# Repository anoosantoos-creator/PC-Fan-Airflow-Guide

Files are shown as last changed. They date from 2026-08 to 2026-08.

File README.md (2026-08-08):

# PC Fan Airflow Guide

A measured 120 mm intake-fan project comparing three internal airflow guides. The repository contains parametric CAD, printable STEP/STL exports, complete OpenFOAM 13 cases, raw rerun evidence, and scripts that recalculate every published table and figure.

The goal is narrow: determine which concepts are worth printing and testing. The CFD does **not** prove lower CPU or GPU temperatures.

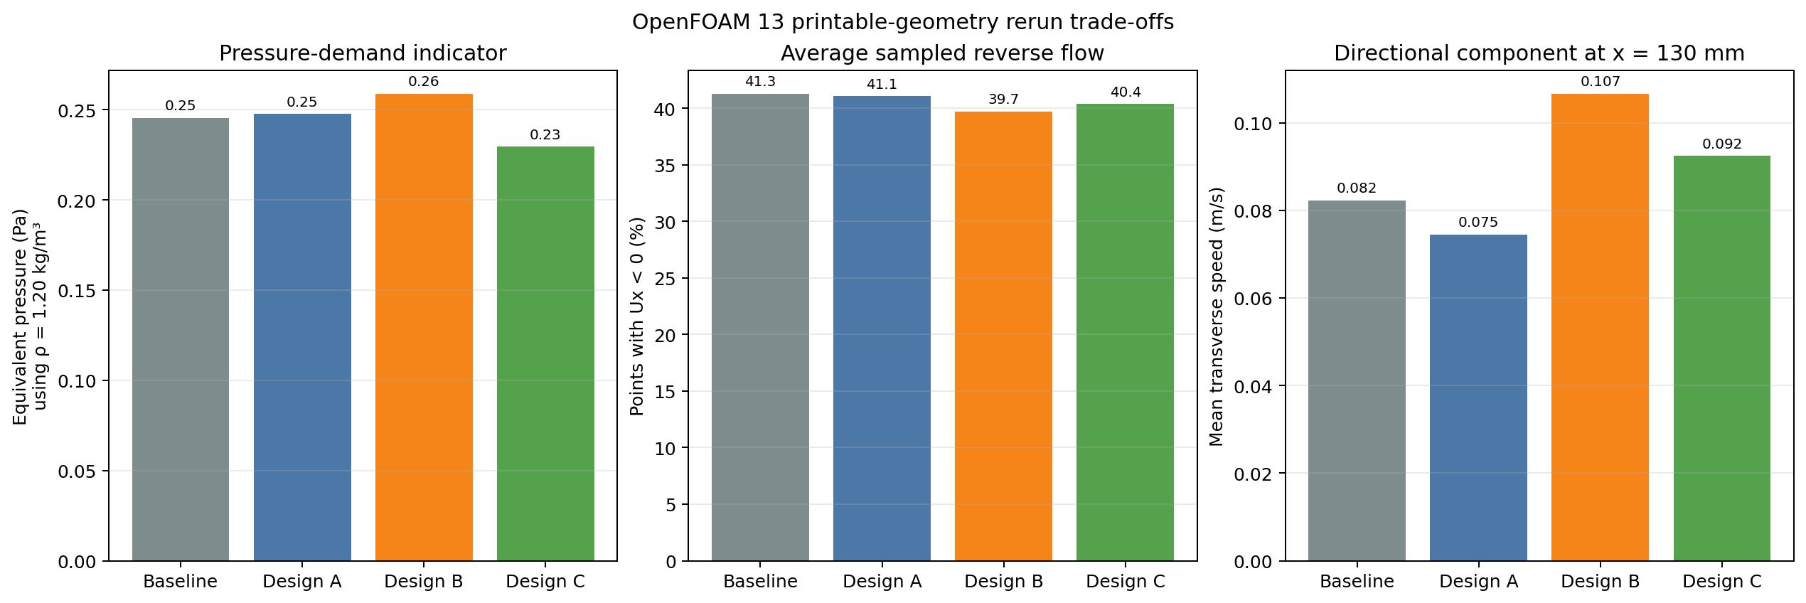
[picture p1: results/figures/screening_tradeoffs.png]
CFD screening trade-offs


## Current result

The printable-geometry rerun leaves two useful physical prototypes:

- **Design A** is the straight-vane control. It has low printable blockage and the smallest mean transverse component at the 130 mm target plane.
- **Design C** is the balanced directional candidate. It has the lowest pressure-demand indicator, low printable blockage, and a transverse component between A and B at 130 mm.
- **Design B** remains the aggressive comparison. It has the lowest average reverse-flow fraction, but also the highest blockage, pressure-demand indicator, and 130 mm transverse component among the guides.

No design is declared final. The next decision requires a baseline-versus-A-versus-C physical test.

| Case | Printable blockage estimate | Pressure-demand indicator* | Mean reverse-flow samples | Transverse speed at 130 mm |
|---|---:|---:|---:|---:|
| Baseline | 0.00% | 0.245 Pa | 41.3% | 0.0823 m/s |
| Design A | 3.95% | 0.248 Pa | 41.1% | 0.0745 m/s |
| Design B | 7.02% | 0.259 Pa | 39.7% | 0.1066 m/s |
| Design C | 3.56% | 0.229 Pa | 40.4% | 0.0924 m/s |

\* OpenFOAM stores kinematic pressure for this incompressible setup. The table converts the sampled pressure difference using an assumed air density of 1.20 kg/m³. Treat it as a comparison indicator, not a fan-pressure measurement.

The full calculation is in [`results/cfd_summary.csv`](results/cfd_summary.csv). Mean axial velocity at 350 mm is within 0.01% across all four cases because the closed duct and equal inlet flow constrain that plane average; it is a mass-flow check, not a design-ranking metric. All four runs reached the 800-iteration limit before satisfying every strict residual control, and no mesh-independence study has been completed. Those limitations are carried into the decision instead of being hidden.

## Designs

| Design | Depth | Vanes | Bias | Vane thickness | Intended role |
|---|---:|---:|---:|---:|---|
| A — low blockage | 20 mm | 6 | 0° | 1.50 mm | Straight-vane control candidate |
| B — angled guide | 25 mm | 8 | 14° | 2.00 mm | High-blockage comparison |
| C — balanced revision | 22 mm | 6 | 9° | 1.35 mm | Balanced directional candidate |

All three printable exports are single connected solids, watertight, manifold, and confined to their declared depth. The vanes overlap both the central hub and outer frame so they do not float as separate bodies.

## Rebuild and check

Requirements:

- Node.js 20 or newer for CAD export
- Python 3.10 or newer for analysis
- OpenFOAM 13 only when rebuilding the CFD solutions

```bash
npm ci
python -m pip install -r requirements.txt
npm run check
```

Individual commands:

```bash
npm run cad
npm run cfd:prepare
npm run analysis
npm run validate
```

To rebuild the meshes and solutions from a clean OpenFOAM 13 shell:

```bash
CFD_JOBS=4 CFD_RUN_ROOT=/path/to/new/run-directory npm run cfd:run
npm run cfd:collect -- /path/to/new/run-directory
npm run analysis
npm run validate
```

The validation step checks STL envelopes and topology, complete case inputs, CAD-to-CFD geometry identity, raw solver evidence, recalculated CFD values, local document links, and the public tree.

## Repository map

- [`cad_designs/`](cad_designs/) — printable STEP/STL files and a dimensional fan reference
- [`scripts/generate_cad.cjs`](scripts/generate_cad.cjs) — parametric CAD source
- [`openfoam_cases/`](openfoam_cases/) — complete OpenFOAM inputs and one-command case runners
- [`data/`](data/) — current and original OpenFOAM target-plane samples and run logs
- [`scripts/run_openfoam_cases.sh`](scripts/run_openfoam_cases.sh) — clean four-case meshing, solving, and sampling pipeline
- [`scripts/analyze_openfoam_samples.py`](scripts/analyze_openfoam_samples.py) — table and figure generation
- [`results/`](results/) — corrected summaries, mesh checks, residuals, and figures
- [`docs/measurements.md`](docs/measurements.md) — measured fan and case constraints
- [`docs/cfd_method.md`](docs/cfd_method.md) — numerical method, provenance, and limitations
- [`docs/physical_test_plan.md`](docs/physical_test_plan.md) — repeatable prototype test procedure
- [`docs/sources.md`](docs/sources.md) — technical references

## Safety and scope

Power the PC down before installation. Confirm blade clearance by hand, secure the guide mechanically, and stop testing if the guide shifts, touches the rotor, or causes abnormal vibration or temperature.

This is an airflow-screening and prototyping project. It is not a certified thermal product or a universal fit for every 120 mm fan.

## License

Released under the [MIT License](LICENSE).

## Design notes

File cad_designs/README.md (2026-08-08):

# CAD Files

All dimensions are millimeters. The x-axis is guide depth; the y-z plane is the 120 × 120 mm fan face.

| File pair | Description | Print status |
|---|---|---|
| `design_A_low_blockage` | 20 mm, six straight 1.5 mm vanes | First-cycle prototype candidate |
| `design_B_angled_guide` | 25 mm, eight 14° biased 2.0 mm vanes | Comparison design; lower priority |
| `design_C_balanced_revision` | 22 mm, six 9° biased 1.35 mm vanes | First-cycle prototype candidate |
| `fan_reference` | Dimensional frame and hub reference | Reference assembly, not a print recommendation |

The three guide STLs are each one connected, watertight manifold component. Their vanes overlap the hub and frame before the final Boolean union. `fan_reference` intentionally contains a separate hub because it represents the fan's inactive center rather than a printable guide.

Regenerate the exports from the repository root:

```bash
npm install
npm run cad
```

Print the guide with a 120 × 120 mm face on the bed and inspect the slicer preview before committing material. Hole fit, screw length, material choice, fan clearance, and case-specific mounting still require a physical check.

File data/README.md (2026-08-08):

# OpenFOAM evidence

The current printable-geometry rerun is stored in `rerun_v2/`:

- `run_manifest.json` records the OpenFOAM build, final iteration, convergence
  status, mesh check, and sampled time for every case.
- `openfoam_logs/` contains the complete meshing, patch-creation, mesh-check,
  solver, and sampling logs.
- `openfoam_samples/` contains the raw x-y-z position, velocity components,
  and kinematic pressure on fixed 50 × 50 grids at the 100, 130, and 350 mm
  target planes.

Each target-plane `.xy` file has seven columns:

```text
point_x point_y point_z U_x U_y U_z p
```

The top-level `openfoam_logs/` and `openfoam_samples/` directories preserve the
original 200-iteration v1 screening evidence. They are retained for provenance
but are no longer the source for the published tables and figures. The v1
printable connectors were revised after those runs, and its original case
dictionaries were unavailable.

The complete v2 inputs are tracked in [`../openfoam_cases/`](../openfoam_cases/).
After a clean solve, `npm run cfd:collect -- /path/to/run-directory` rebuilds
`rerun_v2/` from the completed run. Run `npm run analysis` to rebuild the
public results from that evidence.

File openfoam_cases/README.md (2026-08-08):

# Complete OpenFOAM cases

This directory contains the complete inputs for the current OpenFOAM 13 rerun.
Each case includes initial fields, physical and turbulence properties, meshing
dictionaries, the metre-scale obstruction STL, solver controls, sampling
controls, and an executable `Allrun` script.

| Case | Solid geometry |
|---|---|
| `baseline_no_guide` | Measured fan frame and inactive hub |
| `design_A_low_blockage` | Current connected Design A STL |
| `design_B_angled_guide` | Current connected Design B STL |
| `design_C_balanced_revision` | Current connected Design C STL |

## Rebuild the cases

The tracked case surfaces are deterministic metre-scale copies of the
printable STLs:

```bash
npm run cad
npm run cfd:prepare
```

## Run all four cases

Start an OpenFOAM 13 shell, then run:

```bash
CFD_JOBS=4 CFD_RUN_ROOT=/path/to/new/run-directory npm run cfd:run
```

`CFD_JOBS` may be 1 through 4. The run directory must not already exist. A
temporary directory is created when `CFD_RUN_ROOT` is omitted.

To run one case in place instead:

```bash
cd openfoam_cases/design_A_low_blockage
./Allrun
```

The pipeline executes `blockMesh`, `surfaceCheck`, `snappyHexMesh`,
`createPatch`, `checkMesh`, `foamRun -solver incompressibleFluid`, and
`foamPostProcess`. The native `createPatch` step separates the active
20--52.5 mm inlet annulus from the blocked fan-face area without compiled
boundary code.

## Numerical layout

- Domain: x = -4 to 396 mm; y and z = -100 to 100 mm
- Base mesh: 4 mm cells; local guide refinement down to about 1 mm
- Inlet: 2.5 m/s on the active annulus; blocked elsewhere
- Outlet: fixed kinematic pressure at zero
- Walls and solid geometry: no slip
- Model: steady incompressible RANS with `kOmegaSST`
- Limit: 800 iterations, with residual controls for earlier termination
- Samples: raw `U` and `p` on fixed 50 × 50 grids at x = 100, 130, and 350 mm

Generated meshes and volume fields are run outputs, not case inputs, and are
therefore kept out of the tracked case directories. The dictionaries and
surfaces needed to regenerate them are all included.

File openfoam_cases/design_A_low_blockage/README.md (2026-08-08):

# Design A OpenFOAM case

Current connected 20 mm guide with six straight vanes.

The tracked obstruction surface is a metre-scaled copy of
`cad_designs/design_A_low_blockage.stl`. Run `./Allrun` from an OpenFOAM 13
shell to mesh, solve, and sample the 100, 130, and 350 mm planes.

Case identifier: `design_A_low_blockage`

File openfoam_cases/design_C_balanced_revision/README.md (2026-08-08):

# Design C OpenFOAM case

Current connected 22 mm guide with six 9 degree vanes.

The tracked obstruction surface is a metre-scaled copy of
`cad_designs/design_C_balanced_revision.stl`. Run `./Allrun` from an OpenFOAM 13
shell to mesh, solve, and sample the 100, 130, and 350 mm planes.

Case identifier: `design_C_balanced_revision`

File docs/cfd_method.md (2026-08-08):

# CFD Method

## Question

How do three short guide geometries change the sampled downstream velocity
field and pressure-demand indicator of a measured 120 mm intake-fan setup?

The model screens concepts for prototyping. It does not predict component
temperature.

## Current geometry

The v2 rerun uses the current printable solids rather than the disconnected
vane bodies from the first screening pass.

- Baseline: measured 25 mm fan frame and inactive 40 mm hub
- Design A: current connected 20 mm, six-vane STL
- Design B: current connected 25 mm, eight-vane STL
- Design C: current connected 22 mm, six-vane STL

Every tracked simulation surface is a deterministic metre-scale copy of its
source STL in `cad_designs/`. `surfaceCheck` reports every surface closed; the
three printable guides are each one connected part. The baseline frame and hub
are intentionally two closed parts.

## Domain and boundaries

- Rectangular domain: x = -4 to 396 mm; y and z = -100 to 100 mm
- Physical fan/guide plane: x = 0 mm
- Target planes: x = 100, 130, and 350 mm
- Active inlet annulus: radius 20--52.5 mm
- Active-annulus velocity: 2.5 m/s in the +x direction
- Blocked inlet area, duct sides, and solids: no-slip walls
- Outlet: zero kinematic pressure with an inlet/outlet velocity condition

The 4 mm inlet offset prevents the obstruction surface from being coincident
with a velocity boundary. Extending the outlet to 396 mm keeps the 350 mm
target plane inside the volume instead of sampling on the outlet boundary.
`createPatch` makes the active annulus from native mesh faces, so the setup
does not require compiled boundary code.

The case, cables, coolers, filter, rotor blades, thermal sources, and
manufacturer fan curve are absent. The nominal inlet velocity remains an
equal-input assumption.

## Flow model

- OpenFOAM 13, build recorded in `data/rerun_v2/run_manifest.json`
- Steady incompressible solver module (`foamRun -solver incompressibleFluid`)
- `kOmegaSST` RANS turbulence model
- Kinematic viscosity: 1.5e-5 m²/s
- Inlet turbulence intensity: 5%
- Turbulence mixing length: 4.55 mm
- Maximum 800 SIMPLE iterations
- Residual controls: p = 1e-4; U, k, and omega = 1e-5

The solver can terminate before iteration 800 only when all residual controls
are satisfied. The manifest and residual table distinguish convergence from an
iteration-limit stop for each case. All four published runs reached iteration
800 before satisfying every control; the last residuals remain available in
[`../results/solver_residual_summary.csv`](../results/solver_residual_summary.csv).

## Mesh and sampling

The background mesh uses 4 mm hexahedra. Cells around the fan and guides are
refined, with surface cells down to about 1 mm. Boundary layers are not added.
The pipeline is:

1. `blockMesh`
2. `surfaceCheck`
3. `snappyHexMesh`
4. `createPatch`
5. `checkMesh`
6. `foamRun -solver incompressibleFluid`
7. `foamPostProcess -dict system/sampleDict -latestTime`

All four standard `checkMesh` runs must report `Mesh OK` before their results
are collected. The detailed cell count and quality values are extracted into
[`../results/mesh_quality_summary.csv`](../results/mesh_quality_summary.csv).

The post-processor interpolates `U` and kinematic `p` onto a fixed 50 × 50
cell-center grid at each target plane. The y and z coordinates run from
-98 to 98 mm at 4 mm spacing, so every case is compared at the same 2,500
locations regardless of local mesh refinement. Each row has seven columns:

```text
point_x point_y point_z U_x U_y U_z p
```

## Published metrics

For each plane, the analysis calculates:

- mean axial velocity, mean velocity magnitude, and mean transverse speed
- fraction of points with negative axial velocity
- mean kinematic pressure
- downstream axial retention relative to the v2 baseline

Because every case has the same fixed inlet flow and a closed duct, the
whole-plane downstream mean axial velocity is expected to be nearly identical.
Axial retention is therefore a mass-flow consistency check, not a design
ranking metric. Pressure demand, reverse-flow sampling, and transverse-speed
differences provide the comparative screen.

The pressure-demand indicator is

\[
\left|\overline{p}_{100}-\overline{p}_{350}\right|.
\]

OpenFOAM stores kinematic pressure for this setup. The table multiplies the
indicator by an assumed air density of 1.20 kg/m³ to show an equivalent
pressure in pascals. It is a comparison inside this model, not a fan-pressure
measurement.

## Reproduction

The complete v2 cases are included in [`../openfoam_cases/`](../openfoam_cases/).
They contain every initial field, physical property, turbulence setting,
meshing dictionary, solver control, sampling control, and obstruction surface
needed to rebuild the meshes and rerun the solves. `npm run cfd:run` executes
all four cases; [`../scripts/run_openfoam_cases.sh`](../scripts/run_openfoam_cases.sh)
is the command-level record.

Raw v2 logs and sampled fields are under [`../data/rerun_v2/`](../data/rerun_v2/).
The original v1 evidence remains under the top-level data directories for
provenance, but it is not used for the current figures or tables.

## Interpretation boundary

The rerun supports equal-input comparison of these four local duct models. It
does not establish temperature improvement, a real fan operating point, mesh
independence, turbulence-model independence, or universal fit. A physical
baseline-versus-prototype test remains the deciding experiment.

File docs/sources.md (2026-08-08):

# Technical Sources

## OpenFOAM

- [OpenFOAM 13 release and platform downloads](https://openfoam.org/version/13/)
- [OpenFOAM 13 installation on Ubuntu](https://openfoam.org/download/13-ubuntu/)
- [OpenFOAM on Windows through WSL](https://openfoam.org/download/windows/)
- [OpenFOAM v13 solver modules](https://doc.cfd.direct/openfoam/user-guide-v13/solvers-modules)
- [SIMPLE and solution controls](https://doc.cfd.direct/openfoam/user-guide-v13/fvsolution)
- [`snappyHexMesh` workflow and mesh controls](https://doc.cfd.direct/openfoam/user-guide-v13/snappyhexmesh)
- [Post-processing surfaces and streamlines](https://doc.cfd.direct/openfoam/user-guide-v13/post-processing-functionality)

## Turbulence model

- F. R. Menter, “Two-Equation Eddy-Viscosity Turbulence Models for Engineering Applications,” *AIAA Journal*, 32(8), 1598–1605, 1994. [DOI: 10.2514/3.12149](https://doi.org/10.2514/3.12149)

## Parametric CAD

- [Replicad library setup](https://replicad.xyz/docs/use-as-a-library)
- [Replicad solid export API](https://replicad.xyz/docs/api/classes/Solid/)

## Project-specific evidence

- Direct fan and case measurements are recorded in [`measurements.md`](measurements.md).
- The nominal inlet velocity is an explicit model assumption, not a manufacturer specification.
- Raw sampled fields and solver logs are preserved under [`../data/`](../data/).
- Recalculated tables and residual summaries are preserved under [`../results/`](../results/).

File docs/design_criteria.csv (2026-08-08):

Criterion | Threshold or question | Design A | Design B | Design C | Current evidence
Fit envelope | Remain within the measured 20-25 mm allowance | 20 mm | 25 mm | 22 mm | STL envelopes verified automatically
Single printable body | No floating hub or vane solids | Pass | Pass | Pass | Each guide is one manifold connected component
Geometric blockage | Keep active-annulus obstruction low | 3.95% estimate | 7.02% estimate | 3.56% estimate | Calculated from printable vane span and thickness
Pressure demand | Prefer a lower comparative demand | 0.248 Pa indicator | 0.259 Pa indicator | 0.229 Pa indicator | Design C is lowest in the printable-geometry rerun
Reverse-flow samples | Prefer fewer sampled points with Ux below zero | 41.1% | 39.7% | 40.4% | Average across x=100/130/350 mm; Design B is lowest
Target-plane direction | Compare mean transverse speed at x=130 mm | 0.0745 m/s | 0.1066 m/s | 0.0924 m/s | A is straightest; B is strongest; C is intermediate
Printability | Use robust vane thickness and a flat build orientation | Needs slicer and print check | Lower priority due to thickness and blockage | Needs slicer and print check | CAD topology passes but no physical print is recorded
Mounting | Use positive retention at measured 105 mm spacing | Through-holes | Through-holes | Through-holes | Long screws and nuts or a later clip revision are required
Physical validation | Compare temperature RPM noise and mount stability | Selected | Not first | Selected | Baseline versus A versus C test remains outstanding
Decision | Choose the next prototypes rather than a final winner | Prototype candidate | Retained comparison | Prototype candidate | A tests the straight low-blockage concept; C tests balanced direction with the lowest pressure indicator

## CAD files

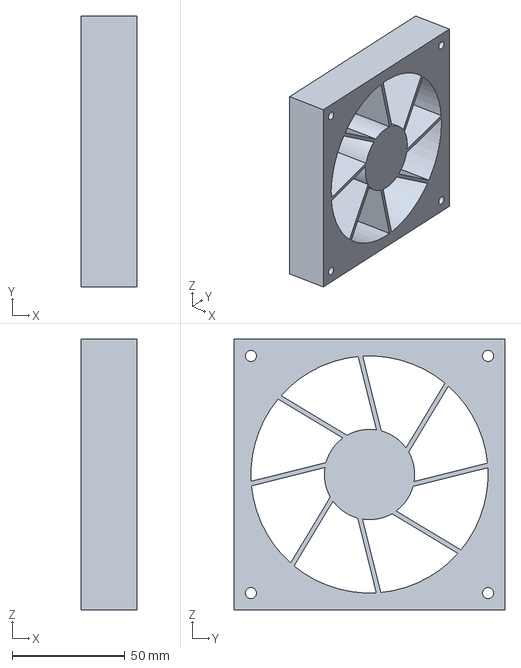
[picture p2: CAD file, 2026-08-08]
cad_designs/design_B_angled_guide.step
25.0 x 120.0 x 120.0 mm

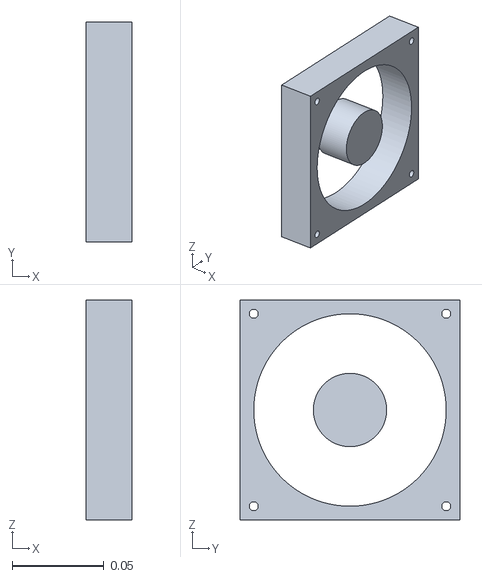
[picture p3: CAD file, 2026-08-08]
openfoam_cases/baseline_no_guide/constant/triSurface/obstruction.stl
0.025 x 0.12 x 0.12

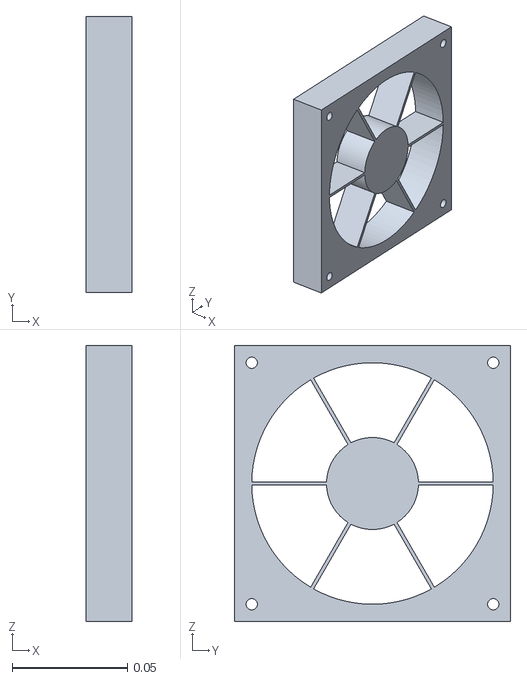
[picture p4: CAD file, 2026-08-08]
openfoam_cases/design_A_low_blockage/constant/triSurface/obstruction.stl
0.02 x 0.12 x 0.12

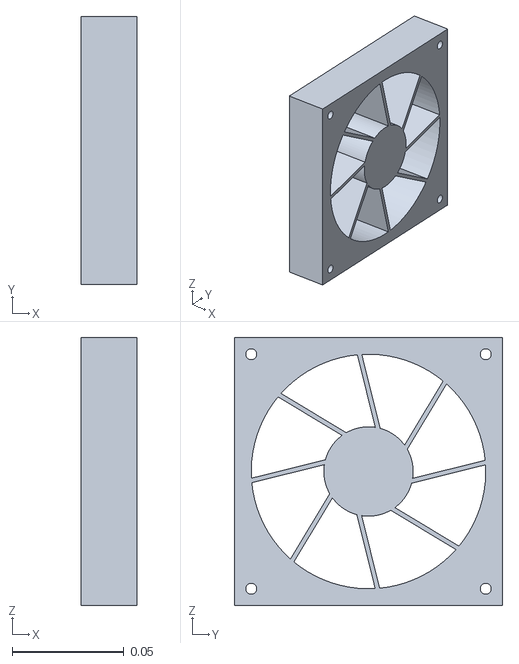
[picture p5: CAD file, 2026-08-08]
openfoam_cases/design_B_angled_guide/constant/triSurface/obstruction.stl
0.025 x 0.12 x 0.12

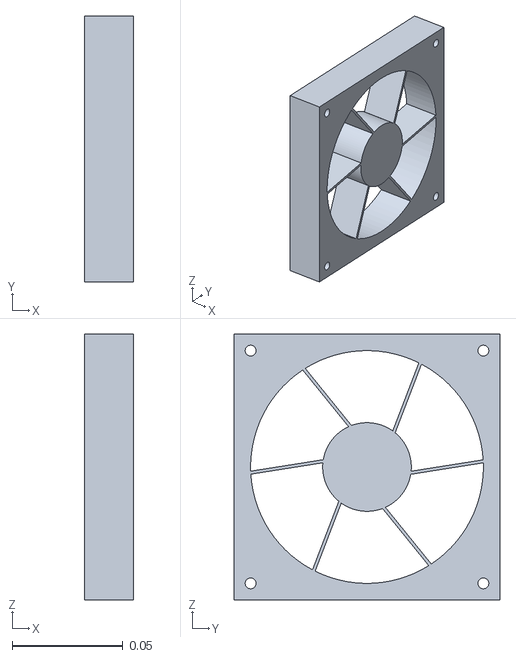
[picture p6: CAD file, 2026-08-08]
openfoam_cases/design_C_balanced_revision/constant/triSurface/obstruction.stl
0.022 x 0.12 x 0.12

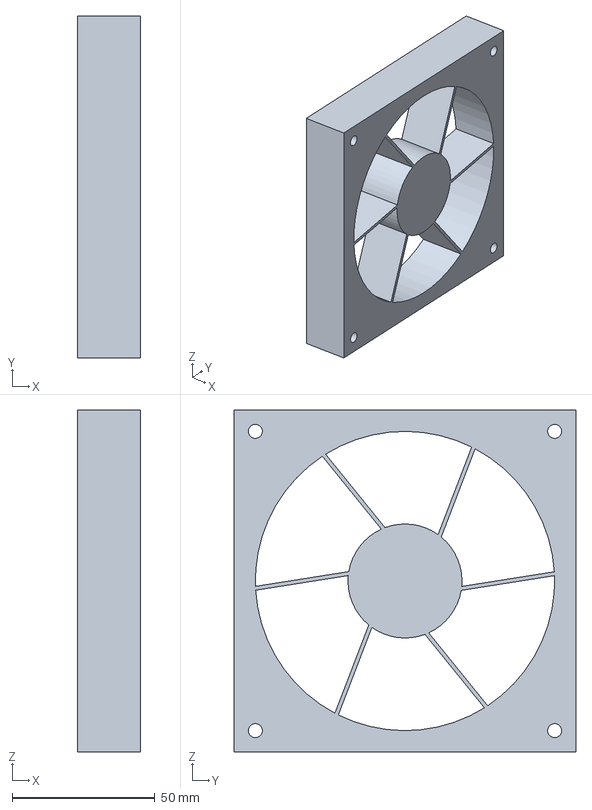
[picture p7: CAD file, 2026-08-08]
cad_designs/design_C_balanced_revision.step
22.0 x 120.0 x 120.0 mm

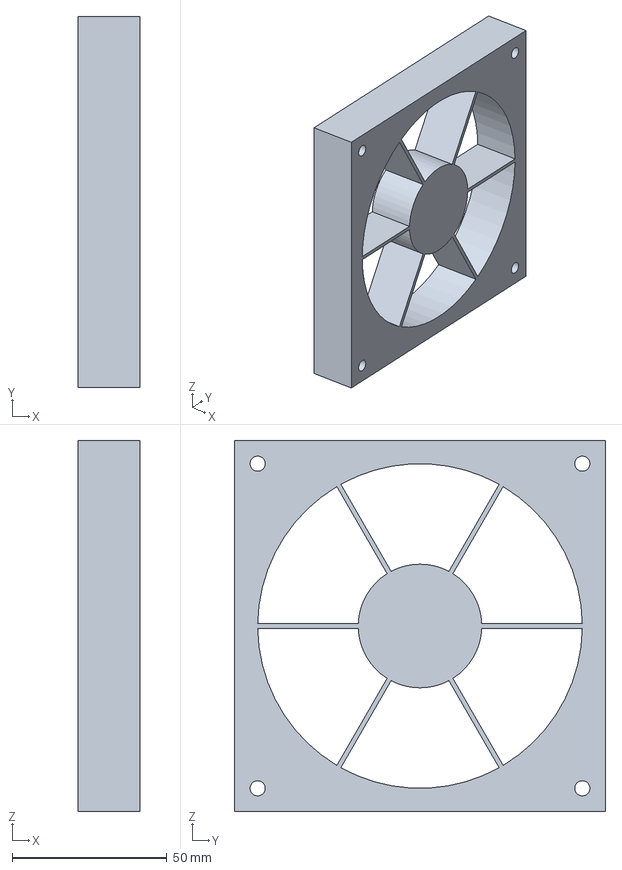
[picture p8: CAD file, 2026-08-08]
cad_designs/design_A_low_blockage.step
20.0 x 120.0 x 120.0 mm

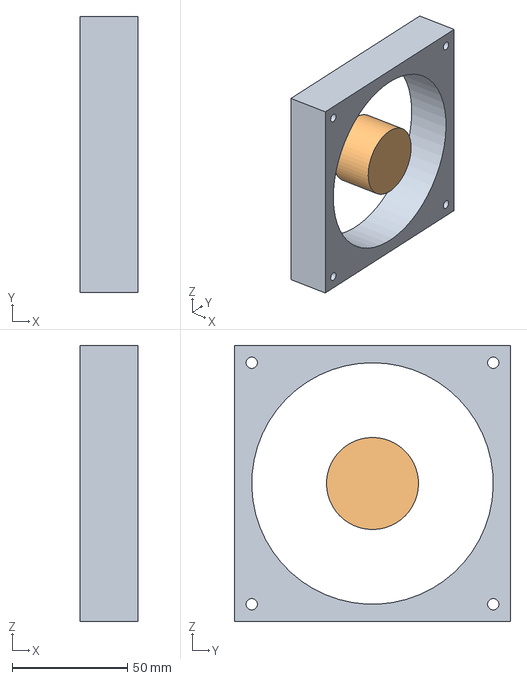
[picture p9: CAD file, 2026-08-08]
cad_designs/fan_reference.step
25.0 x 120.0 x 120.0 mm

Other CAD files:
cad_designs/design_A_low_blockage.stl
cad_designs/design_B_angled_guide.stl
cad_designs/design_C_balanced_revision.stl
cad_designs/fan_reference.stl

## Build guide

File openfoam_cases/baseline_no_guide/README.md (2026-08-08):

# Baseline OpenFOAM case

Measured fan frame and inactive hub, without guide vanes.

The tracked obstruction surface is a metre-scaled copy of
`cad_designs/fan_reference.stl`. Run `./Allrun` from an OpenFOAM 13
shell to mesh, solve, and sample the 100, 130, and 350 mm planes.

Case identifier: `baseline_no_guide`

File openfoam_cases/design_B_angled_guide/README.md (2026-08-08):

# Design B OpenFOAM case

Current connected 25 mm guide with eight 14 degree vanes.

The tracked obstruction surface is a metre-scaled copy of
`cad_designs/design_B_angled_guide.stl`. Run `./Allrun` from an OpenFOAM 13
shell to mesh, solve, and sample the 100, 130, and 350 mm planes.

Case identifier: `design_B_angled_guide`

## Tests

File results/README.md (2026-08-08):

# Results

The tables and figures in this directory are rebuilt from the current OpenFOAM printable-geometry rerun.

- `cfd_summary.csv` — corrected velocity, pressure-demand, reverse-flow, and blockage comparison
- `mesh_quality_summary.csv` — values extracted from each `checkMesh.log`
- `solver_residual_summary.csv` — last-iteration initial residuals and continuity error
- `figures/` — shared-scale velocity maps and the screening trade-off chart

## Interpretation

Design A has the smallest mean transverse component at the 130 mm target plane and retains a low-blockage straight-vane geometry. Design C has the lowest pressure-demand indicator and adds a moderate directional component with slightly lower blockage than A. Design B has the lowest average reverse-flow fraction, but it also has the highest blockage, pressure-demand indicator, and 130 mm transverse component among the guides.

That leaves A and C as deliberately different physical prototypes. The data does not justify naming either one the final design.

The fixed inlet flow makes whole-plane mean axial velocity nearly identical downstream, so axial retention is treated as a mass-flow consistency check rather than a ranking metric. All four runs reached 800 iterations before every strict residual control was satisfied. The residual summary is published because a completed solver log is not the same thing as demonstrated convergence.

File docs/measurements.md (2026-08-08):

# Baseline Measurements

These dimensions were taken from the fan and PC interior before the first design pass.

## Direct measurements

| Item | Value |
|---|---:|
| Fan outer frame | 120 × 120 mm |
| Active blade/opening diameter | 105 mm |
| Central hub diameter | 40 mm |
| Fan thickness | 25 mm |
| Screw-hole spacing | 105 × 105 mm |
| Screw-hole diameter | approximately 4.9 mm |
| Available guide depth | approximately 20–25 mm |
| Fan center to CPU-cooler area | approximately 100 mm |
| Fan center to GPU region | approximately 130 mm |
| Straight internal path after fan | approximately 350 mm |

The fan is installed as an intake. The guide sits inside the case, downstream of the rotor. The intake mesh can be removed.

## Mounting constraint

The internal screw holes are accessible but are not threaded. The CAD therefore uses through-holes at the measured spacing; installation will require longer screws with nuts, another positive-retention fastener, or a later clip revision. A friction-only mount is not acceptable near the rotor.

## Derived CFD input

The measured active annulus is bounded by a 20 mm hub radius and a 52.5 mm opening radius:

\[
A = \pi(0.0525^2 - 0.0200^2) = 0.007402\ \text{m}^2
\]

The current OpenFOAM comparison uses a nominal 2.5 m/s axial inlet over that annulus:

\[
Q = AU \approx 0.0185\ \text{m}^3/\text{s} \approx 39\ \text{CFM}
\]

The velocity is an equal-input assumption for comparing designs. It was not measured from the fan and was not taken from a manufacturer fan curve.

## Evidence still needed

- A ruler/caliper photo for each critical dimension
- An installed-fit photograph showing rotor and component clearance
- The exact fan model and manufacturer pressure-flow data, if available
- A final fastener and retention check before powered testing

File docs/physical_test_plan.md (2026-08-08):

# Physical Test Plan

The CFD screen leaves two useful prototypes: Design A and Design C. This procedure compares them against the unmodified fan without turning a single temperature reading into a cooling claim.

## Configurations

1. Baseline fan with no guide
2. Design A, mounted in the same position
3. Design C, mounted in the same position

Design B is not part of the first print cycle because it combines the highest blockage and pressure-demand indicator with the strongest transverse component at the 130 mm target plane. Its lower reverse-flow fraction remains useful evidence, but does not outweigh those first-cycle trade-offs.

## Controlled conditions

- Same room and PC location
- Same case panels, filter state, cable positions, and fan orientation
- Same fan-control curve or fixed PWM setting
- Same CPU/GPU workload and duration
- Same monitoring software and logging interval
- Same sound-measurement position, if noise is recorded
- A cooldown to a comparable starting temperature before each run

Record ambient temperature. Compare component temperature rise above ambient, not raw temperature alone.

## Procedure

1. Power the PC down and install the configuration.
2. Rotate the fan by hand to confirm full blade clearance.
3. Check that every fastener has positive retention and that the guide cannot shift toward the rotor.
4. Boot the PC and record idle fan RPM, vibration, and unusual noise.
5. Run the same combined CPU/GPU workload for 20 minutes.
6. Log ambient, CPU, GPU, fan RPM, and noise observations once per minute.
7. Use the final five minutes to calculate the steady-state average.
8. Return the system to a comparable starting temperature.
9. Repeat each configuration three times and rotate the test order if time permits.

## Decision fields

- Mechanical fit and blade clearance
- Mount stability after the run
- CPU temperature rise above ambient
- GPU temperature rise above ambient
- Fan RPM at the controlled setting
- New tonal noise, rattle, or vibration
- Repeatability across runs
- Whether observed airflow direction matches the intended guide behavior

## Stop conditions

Stop immediately for rotor contact, guide movement, abnormal vibration, burning smell, unexpected fan stoppage, or a temperature outside the PC's established safe operating range.

The selected design should earn its place through repeatable physical evidence. If neither guide improves the combined thermal/noise result, the baseline remains the correct engineering choice.

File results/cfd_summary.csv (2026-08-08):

case | design | depth_mm | vane_count | vane_bias_deg | vane_thickness_mm | vane_blockage_percent_estimate | mean_ux_x100_m_s | mean_ux_x130_m_s | mean_ux_x350_m_s | axial_retention_x350_percent_of_baseline | mean_speed_x130_m_s | mean_transverse_speed_x130_m_s | mean_speed_x350_m_s | mean_transverse_speed_x350_m_s | kinematic_pressure_demand_m2_s2 | pressure_demand_pa_at_1p2kg_m3 | average_reverse_flow_percent | decision
baseline_no_guide | Baseline | 0.0 | 0 | 0.0 | 0.00 | 0.00 | 0.45860 | 0.46194 | 0.46196 | 100.00 | 0.73356 | 0.08228 | 0.68656 | 0.05172 | 0.20448 | 0.24538 | 41.280 | Reference case
design_A_low_blockage | Design A | 20.0 | 6 | 0.0 | 1.50 | 3.95 | 0.45987 | 0.46206 | 0.46196 | 100.00 | 0.72734 | 0.07453 | 0.69076 | 0.05312 | 0.20629 | 0.24755 | 41.053 | Physical-test candidate
design_B_angled_guide | Design B | 25.0 | 8 | 14.0 | 2.00 | 7.02 | 0.45723 | 0.46207 | 0.46199 | 100.00 | 0.75544 | 0.10663 | 0.68950 | 0.05485 | 0.21567 | 0.25880 | 39.720 | Comparison design
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

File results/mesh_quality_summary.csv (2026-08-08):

case | cells | max_aspect_ratio | max_non_orthogonality_deg | average_non_orthogonality_deg | max_skewness | check_mesh_status
baseline_no_guide | 337119 | 5.0839717 | 49.411631 | 6.0665331 | 1.1508322 | OK
design_A_low_blockage | 355355 | 4.5194497 | 50.595419 | 6.335392 | 1.5519902 | OK
design_B_angled_guide | 365342 | 5.0839714 | 57.006657 | 6.9823907 | 1.986106 | OK
design_C_balanced_revision | 356276 | 4.8465466 | 57.232092 | 6.4384266 | 1.7724191 | OK

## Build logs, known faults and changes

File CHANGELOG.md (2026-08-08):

# Changelog

## 0.2.0 — 2026-08-09

- Added complete OpenFOAM 13 cases for the baseline and all three printable guides.
- Added deterministic case generation, four-case execution, and evidence-collection scripts.
- Rebuilt the meshes from the current STL exports and required every standard `checkMesh` run to report `Mesh OK`.
- Reran all four steady simulations with native annular inlet patches and an 800-iteration limit.
- Rebuilt the published tables and figures from fixed-grid target-plane samples and solver logs.
- Expanded validation to check case completeness, CAD-to-CFD geometry identity, raw sample dimensions, and run evidence.
- Preserved the original screening evidence as provenance while making the printable-geometry rerun the current result set.

## 0.1.0 — 2026-08-08

- Rebuilt all three guide models as single connected solids.
- Extended vanes into the hub and frame so the exports are physically printable.
- Kept Designs A, B, and C within 20 mm, 25 mm, and 22 mm depth envelopes.
- Recalculated pressure as a positive comparison indicator with explicit units.
- Replaced the single-winner claim with an A-versus-C prototype decision.
- Added solver-residual and mesh-quality summaries.
- Replaced misleading streamline filenames with sampled-plane velocity figures.
- Removed local-machine paths and non-public working files.
- Added automated CAD, data, link, and public-text validation.

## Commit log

2026-08-08 Stage verified project snapshot
2026-08-08 Publish corrected PC fan airflow guide
    [cfd_summary.csv, design_A_low_blockage.step, design_A_low_blockage.stl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]
2026-08-08 Normalize generated STEP timestamps
    Regenerate the four STEP exports with the fixed reproducible header timestamp.
    [design_A_low_blockage.step, design_B_angled_guide.step, design_C_balanced_revision.step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]
2026-08-08 Include complete OpenFOAM rerun (#1)
    Add complete rerunnable OpenFOAM 13 cases for the baseline and designs A, B, and C; publish verified 800-iteration mesh, solver, and fixed-grid sampling evidence; regenerate the analysis and figures; and strengthen reproducibility checks.
    All four meshes pass checkMesh and all runs complete without fatal errors. The documented results also state that not every strict residual control was met by iteration 800.
    [cfd_summary.csv, design_criteria.csv, mesh_quality_summary.csv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]
